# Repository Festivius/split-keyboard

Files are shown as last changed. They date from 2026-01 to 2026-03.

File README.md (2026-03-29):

# Split Keyboard

A 52-key wireless split keyboard built based on Hack Club's Blueprint event. The layout is inspired from the Voyager split keyboard.

## Features
- 2 halves made using an nRF52840 board.
- Keyboard matricies with a diode per key to prevent ghosting. 
- Firmware made using ZMK.

## Full Assembly
Screenshot 2026-01-18 at 1 18 55 PM

## CAD Files
Screenshot 2026-01-18 at 1 19 45 PM

## PCB Image
Screenshot 2026-01-22 at 8 19 09 PM

## Schematics
Screenshot 2026-01-22 at 8 19 38 PM
Screenshot 2026-01-22 at 8 19 50 PM

## Cart Screenshots
Screenshot 2026-03-29 at 1 32 01 PM
Screenshot 2026-03-29 at 1 34 22 PM

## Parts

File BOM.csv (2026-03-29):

Item | Quantity | Unit Price ($) | Total Price ($) | Running Total ($CAD with Tax) | Running Total ($USD with Tax) | URL
Gateron Milky Yellow Pro Switches | 52 | 0.53 | 27.40 | 30.69 | 22.10 | https://www.aliexpress.com/item/1005006425450443.html?curPageLogUid=EPGgqbmO0Cnq
1N4148W Diodes | 52 | 0.04 | 2.00 | 32.93 | 23.71 | https://www.aliexpress.com/item/1005007536859190.html?curPageLogUid=TZetvVGMsiOd
Seeed Studio XIAO nRF52840 | 2 | 17.24 | 34.47 | 71.53 | 51.50 | https://www.aliexpress.com/item/1005006988954136.html?curPageLogUid=Ycx7lH26G2Io
PCB | 1 | 24.81 | 24.81 | 99.32 | 71.51 | https://cart.jlcpcb.com/quote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
Blank DSA Keycaps | 50 | 0.43 | 21.30 | 123.18 | 88.69 | https://www.aliexpress.com/item/32842379355.html?curPageLogUid=ZOJj1yK3HMuv
M3 12mm screws | 12 | 0.23 | 2.73 | 126.24 | 90.89 | http://aliexpress.com/item/1005002333132596.html?mp=1
M3 heat inserts | 12 | 0.23 | 2.74 | 129.30 | 93.10 | https://www.aliexpress.com/item/1005003582355741.html?mp=1
Power Switch | 2 | 1.75 | 3.49 | 133.21 | 95.91 | https://www.aliexpress.com/item/1005003938856402.html?curPageLogUid=fMl1OWkF7d3D
1.75u Keycaps | 2 | 4.69 | 9.38 | 143.72 | 103.48 | https://www.aliexpress.com/item/1005007805199854.html?mp=1
Hotswap Sockets | 52 | 0.19 | 9.68 | 154.56 | 111.28 | https://www.aliexpress.com/item/1005007232040760.html?curPageLogUid=Rld8hQgIENFU
3D Printed Case (Top + Bottom | 2 | 0.00 | 0.00 | 154.56 | 111.28 | me!
Batteries | 2 | 6.96 | 13.91 | 170.14 | 122.50 | https://www.aliexpress.com/item/1005010667873043.html?mp=1
Most Current AliExpress Total | 127.34 | 102.69
PCB Total | 12.68 | 9.13
Final Total | 140.02 | 111.82

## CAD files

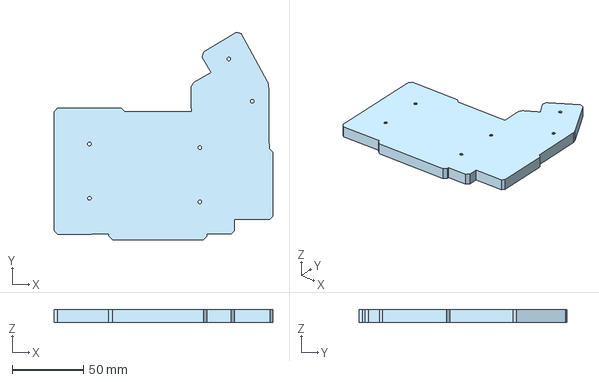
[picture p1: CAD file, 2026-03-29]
case/split-keyboard-case-bottom.step
153.7 x 145.7 x 9.00 mm

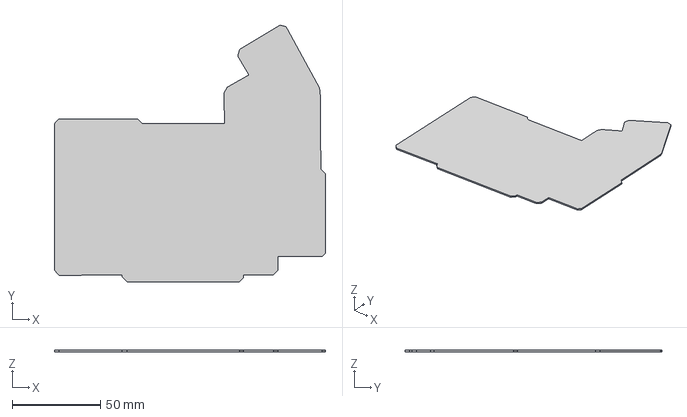
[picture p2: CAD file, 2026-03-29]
case/split-keyboard-case-top.step
153.7 x 145.7 x 1.00 mm

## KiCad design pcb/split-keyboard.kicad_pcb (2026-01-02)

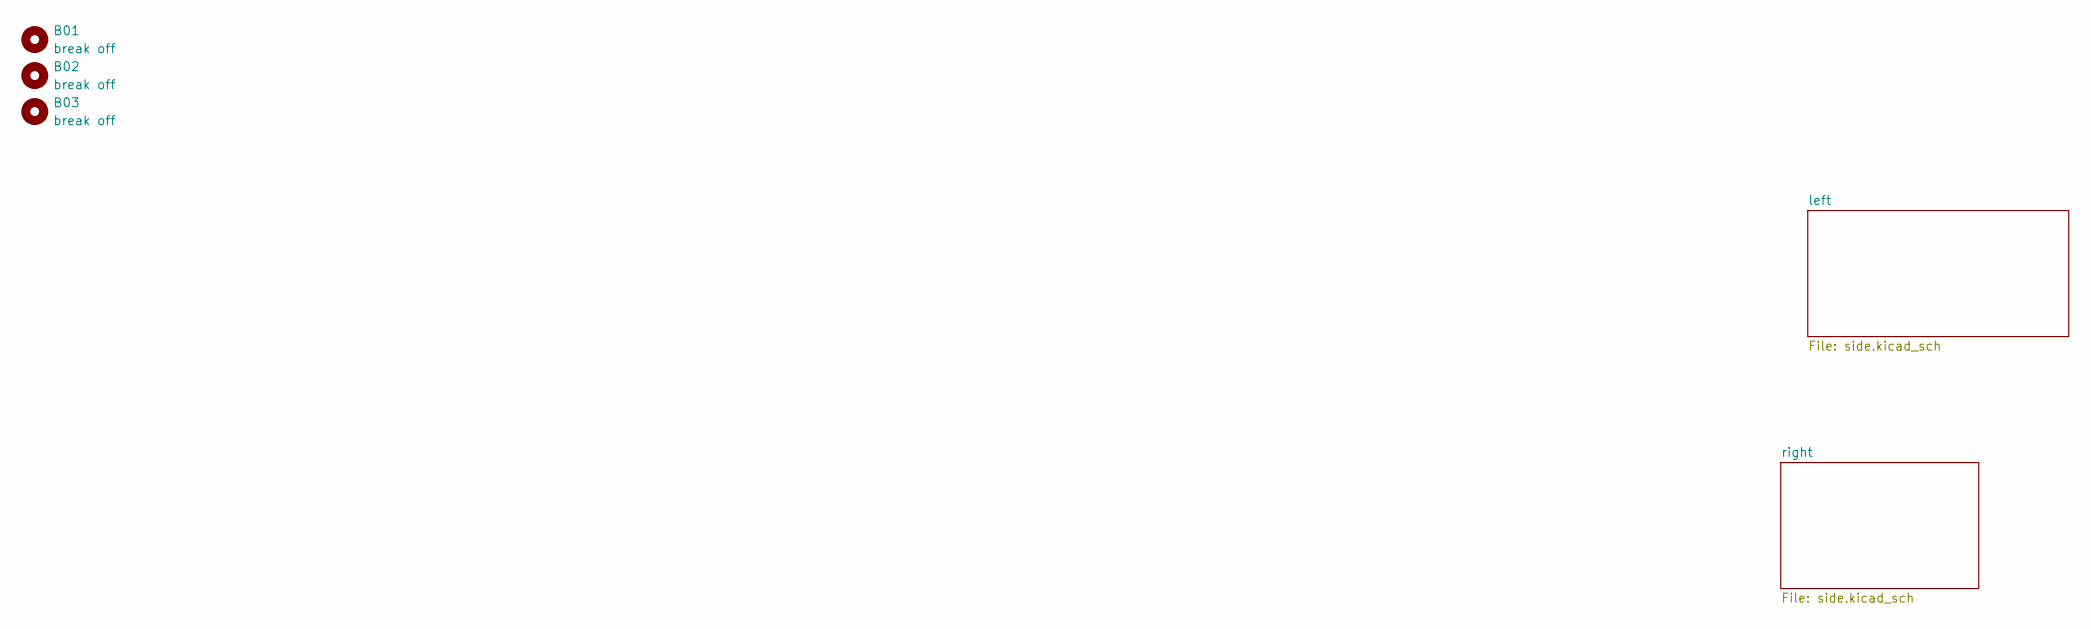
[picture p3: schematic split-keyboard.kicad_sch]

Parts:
B01, B02, B03: break off; mouse-bite-5mm-slot

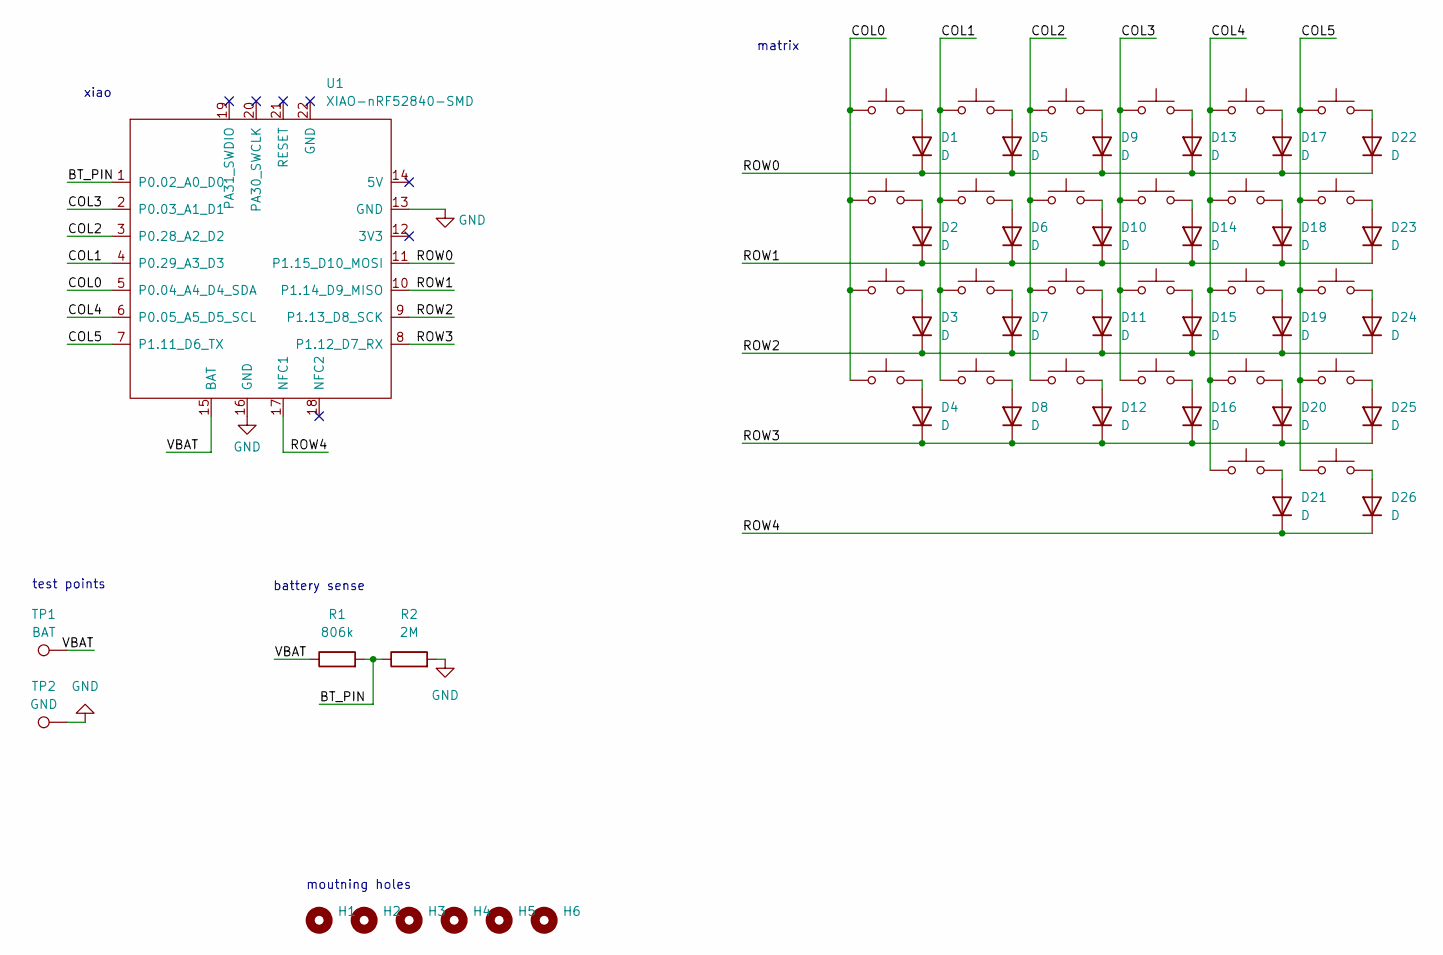
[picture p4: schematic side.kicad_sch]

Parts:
D1, D2, D3, D4, D5, D6, D7, D8, D9, D10, D11, D12, D13, D14, D15, D16, D17, D18, D19, D20, D21, D22, D23, D24, D25, D26: D; D_SOD-123
H1, H2, H3, H4, H5, H6: MountingHole; MountingHole_2.7mm_M2.5
R1: 806k; R_0805_2012Metric
R2: 2M; R_0805_2012Metric
SW1, SW2, SW3, SW4, SW5, SW6, SW7, SW8, SW9, SW10, SW11, SW12, SW13, SW14, SW15, SW16, SW17, SW18, SW19, SW20, SW21, SW22, SW23, SW24, SW25: SW_Push; SW_MX_HS_KS-2P02B01-01_1u
SW26: SW_Push; SW_MX_HS_KS-2P02B01-01_1.75u
TP1: BAT; TestPoint_Pad_D4.0mm
TP2: GND; TestPoint_Pad_D4.0mm
U1: XIAO-nRF52840-SMD; modified-XIAO-nRF52840-SMD

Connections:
/left/BT_PIN: R1.2, R2.1, U1.1 (P0.02_A0_D0)
/left/COL0: SW1.1, SW2.1, SW3.1, SW4.1, U1.5 (P0.04_A4_D4_SDA)
/left/COL1: SW5.1, SW6.1, SW7.1, SW8.1, U1.4 (P0.29_A3_D3)
/left/COL2: SW9.1, SW10.1, SW11.1, SW12.1, U1.3 (P0.28_A2_D2)
/left/COL3: SW13.1, SW14.1, SW15.1, SW16.1, U1.2 (P0.03_A1_D1)
/left/COL4: SW17.1, SW18.1, SW19.1, SW20.1, SW21.1, U1.6 (P0.05_A5_D5_SCL)
/left/COL5: SW22.1, SW23.1, SW24.1, SW25.1, SW26.1, U1.7 (P1.11_D6_TX)
/left/ROW0: D1.1 (K), D5.1 (K), D9.1 (K), D13.1 (K), D17.1 (K), D22.1 (K), U1.11 (P1.15_D10_MOSI)
/left/ROW1: D2.1 (K), D6.1 (K), D10.1 (K), D14.1 (K), D18.1 (K), D23.1 (K), U1.10 (P1.14_D9_MISO)
/left/ROW2: D3.1 (K), D7.1 (K), D11.1 (K), D15.1 (K), D19.1 (K), D24.1 (K), U1.9 (P1.13_D8_SCK)
/left/ROW3: D4.1 (K), D8.1 (K), D12.1 (K), D16.1 (K), D20.1 (K), D25.1 (K), U1.8 (P1.12_D7_RX)
/left/ROW4: D21.1 (K), D26.1 (K), U1.17 (NFC1)
/left/VBAT: R1.1, TP1.1, U1.15 (BAT)
GND: R2.2, TP2.1, U1.13 (GND), U1.16 (GND); also elsewhere on the board
unnamed: D1.2 (A), SW1.2
unnamed: D2.2 (A), SW2.2
unnamed: D3.2 (A), SW3.2
unnamed: D4.2 (A), SW4.2
unnamed: D5.2 (A), SW5.2
unnamed: D6.2 (A), SW6.2
unnamed: D7.2 (A), SW7.2
unnamed: D8.2 (A), SW8.2
unnamed: D9.2 (A), SW9.2
unnamed: D10.2 (A), SW10.2
unnamed: D11.2 (A), SW11.2
unnamed: D12.2 (A), SW12.2
unnamed: D13.2 (A), SW13.2
unnamed: D14.2 (A), SW14.2
unnamed: D15.2 (A), SW15.2
unnamed: D16.2 (A), SW16.2
unnamed: D17.2 (A), SW17.2
unnamed: D18.2 (A), SW18.2
unnamed: D19.2 (A), SW19.2
unnamed: D20.2 (A), SW20.2
unnamed: D21.2 (A), SW21.2
unnamed: D22.2 (A), SW22.2
unnamed: D23.2 (A), SW23.2
unnamed: D24.2 (A), SW24.2
unnamed: D25.2 (A), SW25.2
unnamed: D26.2 (A), SW26.2

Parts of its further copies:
D27, D28, D29, D30, D31, D32, D33, D34, D35, D36, D37, D38, D39, D40, D41, D42, D43, D44, D45, D46, D47, D48, D49, D50, D51, D52: D; D_SOD-123
H7, H8, H9, H10, H11, H12: MountingHole; MountingHole_2.7mm_M2.5
R3: 806k; R_0805_2012Metric
R4: 2M; R_0805_2012Metric
SW27, SW28, SW29, SW30, SW31, SW32, SW33, SW34, SW35, SW36, SW37, SW38, SW39, SW40, SW41, SW42, SW43, SW44, SW45, SW46, SW47, SW48, SW49, SW50, SW51: SW_Push; SW_MX_HS_KS-2P02B01-01_1u
SW52: SW_Push; SW_MX_HS_KS-2P02B01-01_1.75u
TP3: BAT; TestPoint_Pad_D4.0mm
TP4: GND; TestPoint_Pad_D4.0mm
U2: XIAO-nRF52840-SMD; modified-XIAO-nRF52840-SMD

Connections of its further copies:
/right/BT_PIN: R3.2, R4.1, U2.1 (P0.02_A0_D0)
/right/COL0: SW27.1, SW28.1, SW29.1, SW30.1, U2.5 (P0.04_A4_D4_SDA)
/right/COL1: SW31.1, SW32.1, SW33.1, SW34.1, U2.4 (P0.29_A3_D3)
/right/COL2: SW35.1, SW36.1, SW37.1, SW38.1, U2.3 (P0.28_A2_D2)
/right/COL3: SW39.1, SW40.1, SW41.1, SW42.1, U2.2 (P0.03_A1_D1)
/right/COL4: SW43.1, SW44.1, SW45.1, SW46.1, SW47.1, U2.6 (P0.05_A5_D5_SCL)
/right/COL5: SW48.1, SW49.1, SW50.1, SW51.1, SW52.1, U2.7 (P1.11_D6_TX)
/right/ROW0: D27.1 (K), D31.1 (K), D35.1 (K), D39.1 (K), D43.1 (K), D48.1 (K), U2.11 (P1.15_D10_MOSI)
/right/ROW1: D28.1 (K), D32.1 (K), D36.1 (K), D40.1 (K), D44.1 (K), D49.1 (K), U2.10 (P1.14_D9_MISO)
/right/ROW2: D29.1 (K), D33.1 (K), D37.1 (K), D41.1 (K), D45.1 (K), D50.1 (K), U2.9 (P1.13_D8_SCK)
/right/ROW3: D30.1 (K), D34.1 (K), D38.1 (K), D42.1 (K), D46.1 (K), D51.1 (K), U2.8 (P1.12_D7_RX)
/right/ROW4: D47.1 (K), D52.1 (K), U2.17 (NFC1)
/right/VBAT: R3.1, TP3.1, U2.15 (BAT)
GND: R4.2, TP4.1, U2.13 (GND), U2.16 (GND); also elsewhere on the board
unnamed: D27.2 (A), SW27.2
unnamed: D28.2 (A), SW28.2
unnamed: D29.2 (A), SW29.2
unnamed: D30.2 (A), SW30.2
unnamed: D31.2 (A), SW31.2
unnamed: D32.2 (A), SW32.2
unnamed: D33.2 (A), SW33.2
unnamed: D34.2 (A), SW34.2
unnamed: D35.2 (A), SW35.2
unnamed: D36.2 (A), SW36.2
unnamed: D37.2 (A), SW37.2
unnamed: D38.2 (A), SW38.2
unnamed: D39.2 (A), SW39.2
unnamed: D40.2 (A), SW40.2
unnamed: D41.2 (A), SW41.2
unnamed: D42.2 (A), SW42.2
unnamed: D43.2 (A), SW43.2
unnamed: D44.2 (A), SW44.2
unnamed: D45.2 (A), SW45.2
unnamed: D46.2 (A), SW46.2
unnamed: D47.2 (A), SW47.2
unnamed: D48.2 (A), SW48.2
unnamed: D49.2 (A), SW49.2
unnamed: D50.2 (A), SW50.2
unnamed: D51.2 (A), SW51.2
unnamed: D52.2 (A), SW52.2

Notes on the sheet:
battery sense
test points
moutning holes
xiao
matrix

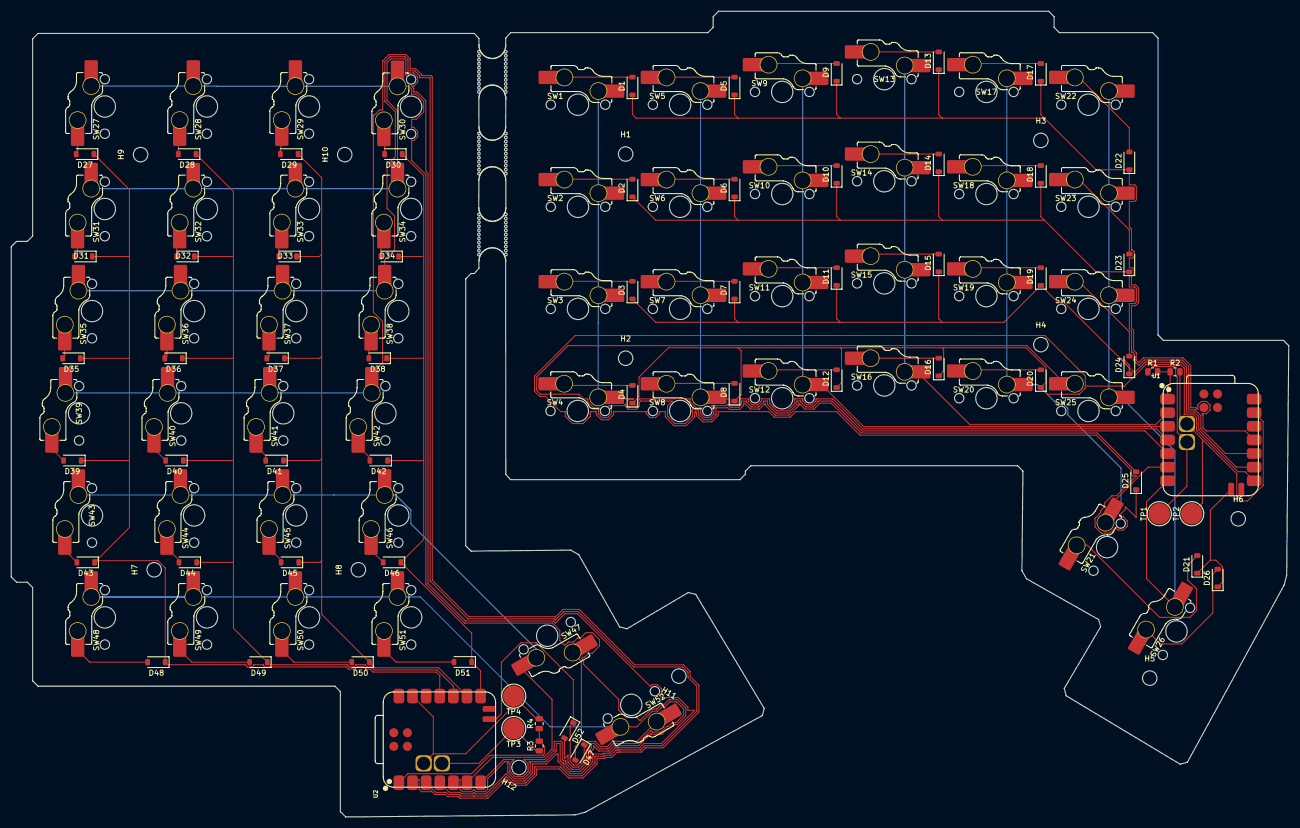
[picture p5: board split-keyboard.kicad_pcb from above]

Board: 2 copper layers, 238.4 x 150.3 mm, 129 parts (0 on the bottom side), 79 nets.

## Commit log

2026-01-02 added pcb
    [side.kicad_sch, split-keyboard.kicad_pcb, split-keyboard.kicad_sch]
2026-01-02 moved pcb to folder
    [side.kicad_sch, split-keyboard.kicad_pcb, split-keyboard.kicad_sch]
2026-01-23 Add project details for split keyboard
    Added detailed information about the split keyboard project, including assembly, CAD files, PCB image, schematics, and BOM link.
2026-03-29 Replace BOM Google Spreadsheet section with Cart Screenshots
